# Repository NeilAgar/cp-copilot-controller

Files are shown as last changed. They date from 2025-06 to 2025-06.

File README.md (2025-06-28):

# Open-Source Assistive "Copilot" Controller

> A durable, low-cost compliant mechanism controller designed for users with spasticity. It uses advanced signal processing to filter out involuntary tremors and includes a "split-control" feature for cooperative gaming, also letting you play on your switch with a computer.

---

Fully assembled controller next to Nintendo Switch

## Table of Contents

* [The Problem & Solution](#the-problem--solution)
* [Getting Started](#getting-started)
* [Bill of Materials (BOM)](#bill-of-materials-bom)
* [3D Printing/Fabrication](#3d-printingfabrication)
* [Assembly](#assembly)

* [Firmware and Software](#firmware-and-software)
* [Flashing the ESP32 Firmware](#flashing-the-esp32-firmware)
* [Setting up the PC "Copilot" App](#setting-up-the-pc-copilot-app)

* [Usage](#usage)
* [How it Works (Technical Details)](#how-it-works-technical-details)

---

## The Problem & Solution

Traditional mechanical accessibility switches are often expensive, fragile, and fail to account for spastic movements. For users with conditions like Cerebral Palsy, high-impact involuntary movements can break standard hinges or register erratic false inputs.

**The Solution:** This controller replaces mechanical parts with a 3D-printed compliant mechanism (a solid-state spring that flexes) and capacitive sensing. Instead of a simple on/off switch, the onboard ESP32-S3 uses a Kalman filter and adaptive algorithms to distinguish between intentional presses and spastic tremors in real-time.

It also features a **"Split-Control Bridge,"** allowing a partner to handle navigation tasks (like movement) via Wi-Fi from a PC, while the user controls primary actions on the controller.

---

## Getting Started

### Bill of Materials (BOM)

You can purchase all necessary components via this **[Amazon Wishlist](https://www.amazon.com/hz/wishlist/ls/JKSAYW0141NF?ref_=wl_share)**.

| Item | Description | Qty | Note |
| --- | --- | --- | --- |
| **Microcontroller** | ESP32-S3 Dev Board OR Adafruit Metro ESP32-S3 | 1 | The Adafruit board is easier to wire but costs slightly more. Only choose one! |
| **Wires** | 22-24 AWG Stranded Wire to connect components & the foil |
| **Potentiometer** | 10k Potentiometer (Optional) | 1 | Allows for on-the-fly sensitivity adjustment. |
| **Sensor Material** | Aluminum Foil | Small Square | Kitchen foil works perfectly. |

### 3D Printing/Fabrication

The design uses a compliant mechanism, so it must be printed in **PETG** or **PLA+** for durability. Do not use standard brittle PLA.

**Option 1: Print it yourself**
Choose the files matching your microcontroller.

* **For Generic ESP32-S3:**
* [Download STLs](print_files/ESP32-prints.zip)
* [Download 3MF (OrcaSlicer)](print_files/Print-ESP32.3mf)

* **For Adafruit Metro ESP32-S3:**
* [Download STLs](print_files/Adafruit-prints.zip)
* [Download 3MF (OrcaSlicer)](print_files/Print-Adafruit.3mf)

**Option 2: Order printed parts (If you don't own a printer)**
Use these links to order the parts directly through CraftCloud.

* [Order parts for Generic ESP32-S3 Version](https://craftcloud3d.com/configuration/b1fc5dbd-c97f-46f4-a522-1355bb4c70ae)
* [Order parts for Adafruit Metro Version](https://craftcloud3d.com/configuration/f809734d-5e56-4cc8-a2c9-b1faf550a3c4)

### Assembly

Detailed assembly instructions and video guides can be found here:
**[View Assembly Guide & Pictures (Google Drive)](https://drive.google.com/drive/folders/16ZFhgrj6qlABAafDJcucosywIMY7Crnk)**

---

## Firmware and Software

### Flashing the ESP32 Firmware

1. Download and install the [Arduino IDE](https://www.arduino.cc/en/software).
2. Follow instructions online to add `esp32` board support to your IDE.
3. Download the firmware file from this repo: [`copilot_firmware.ino`](copilot_firmware.ino).
4. Open the `.ino` file in Arduino IDE. Select your board type (e.g., "Adafruit Metro ESP32-S3" or "ESP32S3 Dev Module") and the correct COM port.
5. Click **Upload** (the arrow pointing to the right).

> **Troubleshooting:** If the upload fails to connect, hold down the **BOOT** button on your ESP32 board, press and release the **RESET** button, then release the **BOOT** button. Hit upload again.

### Setting up the PC "Copilot" App

This Python script allows a partner on a PC to send navigation inputs to the controller over Wi-Fi.

1. Download and install [Python](https://www.python.org/downloads/) (ensure you check "Add Python to PATH" during installation).
2. Open your command prompt or terminal and install the required library:
```bash
pip install pygame
```

3. Download the controller script: [`controller.py`](controller.py).

---

## Usage

1. **Connect Hardware:** Plug the finished controller into your Nintendo Switch dock or PC via USB-C. It will be recognized as a wired Pro Controller.
2. **Connect Network:** On your PC laptop, connect to the Wi-Fi network named `MarioCopilot` (Password: `12345678`).
3. **Run Bridge:** On your PC, run the Python script. A window will appear showing controller status.
```bash
python controller.py
```

4. **Play:** The user presses the main button on the controller for actions (e.g., Jump), while the partner uses the PC keyboard (WASD/Arrow Keys) for movement.

---

## How it Works (Technical Details)

This device addresses the "noisy signal" problem inherent in spasticity. Involuntary tremors can cause standard capacitive sensors to trigger falsely.

Instead of a simple threshold, this firmware runs a **1-Dimensional Kalman Filter** on the raw sensor data. This mathematical algorithm estimates the true intent of the user by smoothing out high-frequency jitter (tremors) while responding quickly to significant changes (intentional presses).

Furthermore, the system uses an adaptive baseline that constantly re-calibrates to changing environmental conditions like humidity or temperature drift, ensuring consistent performance without manual recalibration.

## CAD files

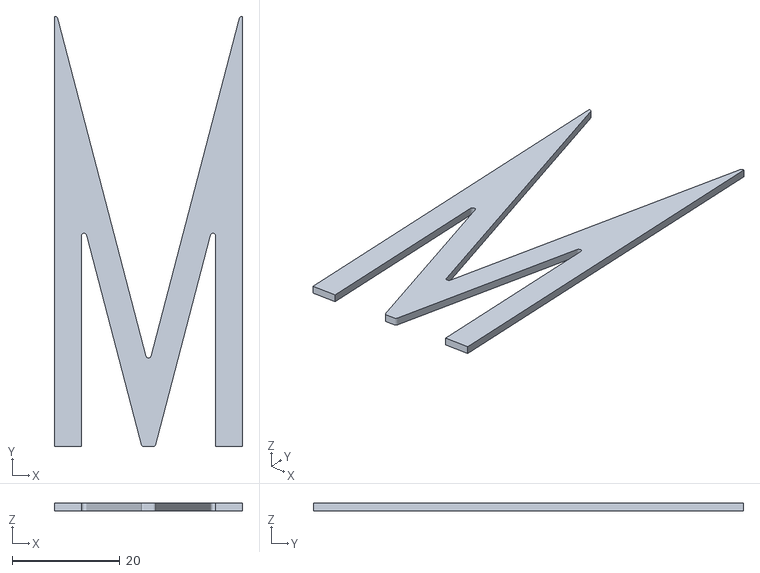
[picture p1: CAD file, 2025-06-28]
print_files/Spring.stl
35.0 x 80.0 x 1.40

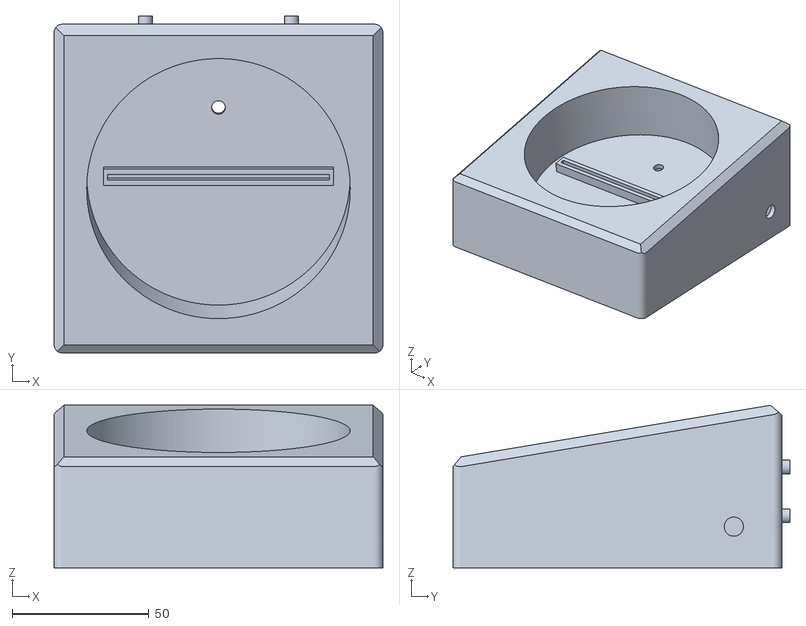
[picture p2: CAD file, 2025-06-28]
print_files/Frame-ESP32.stl
120.0 x 123.0 x 59.3

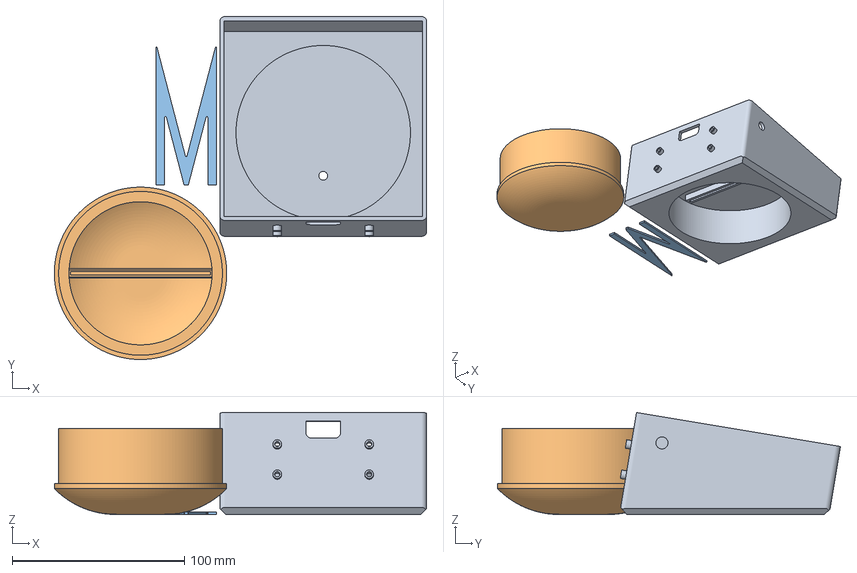
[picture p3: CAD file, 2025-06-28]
print_files/Print-ESP32.3mf
216.0 x 199.0 x 59.2 mm
Frame-ESP32.stl
Button Cap.stl
Spring.stl

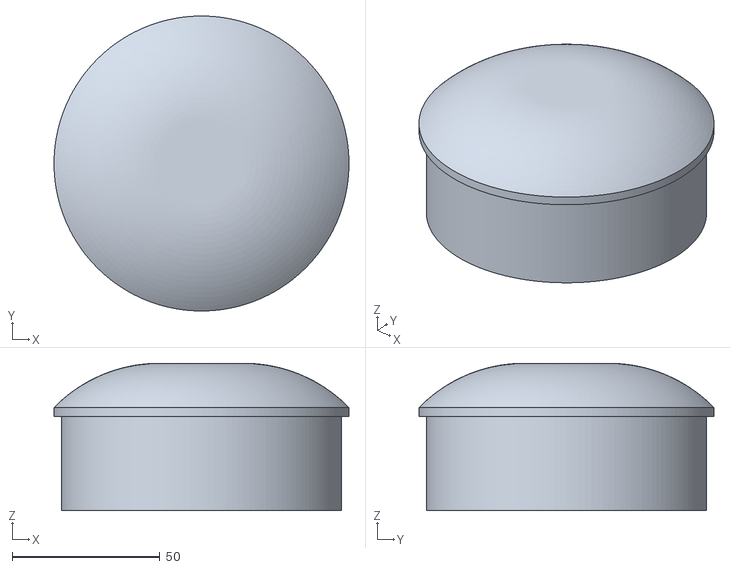
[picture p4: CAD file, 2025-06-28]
print_files/Button Cap.stl
100.0 x 100.0 x 50.0

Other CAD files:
print_files/Frame-Adafruit.stl
print_files/Print-Adafruit.3mf

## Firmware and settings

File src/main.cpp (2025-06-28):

#include "switch_ESP32.h"
#include <Arduino.h>
#include <WiFi.h>
#include <WiFiUdp.h>

NSGamepad Gamepad;
WiFiUDP udp;

// --- CONFIG ---
const char *ssid = "MarioCopilot";
const char *password = "12345678";
const int UDP_PORT = 4210;

// --- PINS ---
const int PIN_TOUCH = 4;
const int PIN_POT = 14;

// --- VARIABLES ---
// UDP Data Containers
int udp_LX = 128;
int udp_LY = 128;
int udp_RX = 128;
int udp_RY = 128;
uint8_t udp_Btns = 0; // Bitmask

unsigned long lastPacketTime = 0;
float steadyBaseline = 0;
bool isLocalPressed = false;
float smoothedTouch = 0;

// --- KALMAN FILTER ---
class SimpleKalmanFilter {
  private:
    float _err_measure, _err_estimate, _q, _last_estimate, _kalman_gain;
  public:
    SimpleKalmanFilter(float mea_e, float est_e, float q) {
      _err_measure = mea_e; _err_estimate = est_e; _q = q;
    }
    float updateEstimate(float mea) {
      _kalman_gain = _err_estimate / (_err_estimate + _err_measure);
      float current_estimate = _last_estimate + _kalman_gain * (mea - _last_estimate);
      _err_estimate = (1.0 - _kalman_gain) * _err_estimate + fabs(_last_estimate - current_estimate) * _q;
      _last_estimate = current_estimate;
      return current_estimate;
    }
};

SimpleKalmanFilter kf(5.0, 5.0, 0.01); 

void setup() {
  // 1. Init System
  Gamepad.begin();
  USB.begin();
  
  // 2. Init Network
  WiFi.softAP(ssid, password);
  udp.begin(UDP_PORT);

  // 3. Calibrate Local Sensor
  long total = 0;
  for(int i=0; i<50; i++) {
    total += touchRead(PIN_TOUCH);
    delay(5);
  }
  steadyBaseline = total / 50.0;
  smoothedTouch = steadyBaseline;
}

void loop() {
  // 1. Receive PC Data (5 Bytes)
  int packetSize = udp.parsePacket();
  if (packetSize >= 5) {
    uint8_t packet[5];
    udp.read(packet, 5);
    
    udp_LX = packet[0];
    udp_LY = packet[1];
    udp_RX = packet[2];
    udp_RY = packet[3];
    udp_Btns = packet[4];
    
    lastPacketTime = millis();
  }

  // If PC disconnects (>500ms), reset everything
  if (millis() - lastPacketTime > 500) {
    udp_LX = 128; udp_LY = 128;
    udp_RX = 128; udp_RY = 128;
    udp_Btns = 0;
  }

  // 2. Local Sensor Logic
  int rawPot = analogRead(PIN_POT);
  float rawTouch = touchRead(PIN_TOUCH);
  smoothedTouch = kf.updateEstimate(rawTouch);

  // Drift Correction
  if (abs(smoothedTouch - steadyBaseline) < 5000) {
    steadyBaseline = (steadyBaseline * 0.95) + (smoothedTouch * 0.05);
  }

  // Threshold Calculation
  float thresholdOffset = map(rawPot, 0, 4096, 1000, 8000);
  float triggerPoint = steadyBaseline + thresholdOffset;
  float releasePoint = steadyBaseline + (thresholdOffset * 0.8);

  // 3. Apply

  // A. Local User Input
  // don't override the PC if it presses A too
  if (!isLocalPressed) {
    if (smoothedTouch > triggerPoint) {
      isLocalPressed = true;
      Gamepad.press(NSButton_A);
    }
  } else {
    if (smoothedTouch < releasePoint) {
      isLocalPressed = false;
      // Only release if the PC isnt also holding A (Bit 0)
      if ((udp_Btns & 1) == 0) {
        Gamepad.release(NSButton_A);
      }
    }
  }

  // B. PC Joystick Inputs
  Gamepad.leftXAxis(udp_LX);
  Gamepad.leftYAxis(udp_LY);
  Gamepad.rightXAxis(udp_RX);
  Gamepad.rightYAxis(udp_RY);

  // C. PC Button Inputs Bitmask
  
  // Bit 0: A (Handled in Local logic above to merge signals)
  if ((udp_Btns & 1) && !isLocalPressed) Gamepad.press(NSButton_A);
  
  // Bit 1: B
  if (udp_Btns & 2) Gamepad.press(NSButton_B); else Gamepad.release(NSButton_B);
  
  // Bit 2: X
  if (udp_Btns & 4) Gamepad.press(NSButton_X); else Gamepad.release(NSButton_X);
  
  // Bit 3: Y
  if (udp_Btns & 8) Gamepad.press(NSButton_Y); else Gamepad.release(NSButton_Y);
  
  // Bit 4: L
  if (udp_Btns & 16) Gamepad.press(NSButton_LeftTrigger); else Gamepad.release(NSButton_LeftTrigger);
  
  // Bit 5: R
  if (udp_Btns & 32) Gamepad.press(NSButton_RightTrigger); else Gamepad.release(NSButton_RightTrigger);
  
  // Bit 6: ZL
  if (udp_Btns & 64) Gamepad.press(NSButton_LeftThrottle); else Gamepad.release(NSButton_LeftThrottle);
  
  // Bit 7: ZR
  if (udp_Btns & 128) Gamepad.press(NSButton_RightThrottle); else Gamepad.release(NSButton_RightThrottle);

  // 4. Send
  Gamepad.loop();
  delay(5);
}

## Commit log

2025-05-30 Compat with Switch
2025-06-28 Added controller picture
    [Button Cap.stl, Frame-Adafruit.stl, Frame-ESP32.stl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]
